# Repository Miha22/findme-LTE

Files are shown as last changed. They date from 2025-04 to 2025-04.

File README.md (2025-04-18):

# Low power LTE & GNSS anti-theft tracker

This project contains hardware design files, including schematics and PCB layouts created by Deniel.  
It is shared for educational and personal use purposes only. Commercial use is not permitted without written permission.

## Preview

The previews of the PCB design and schematic:

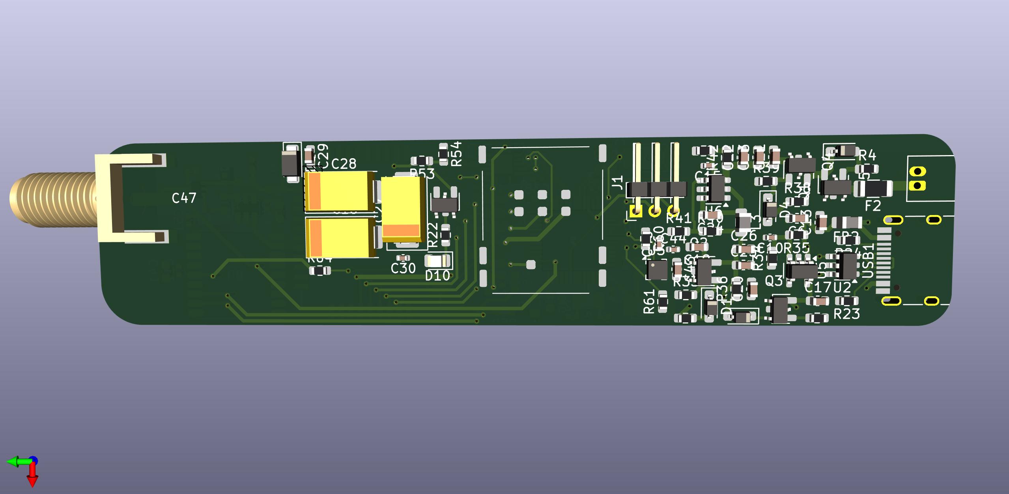
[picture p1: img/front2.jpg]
Board Front

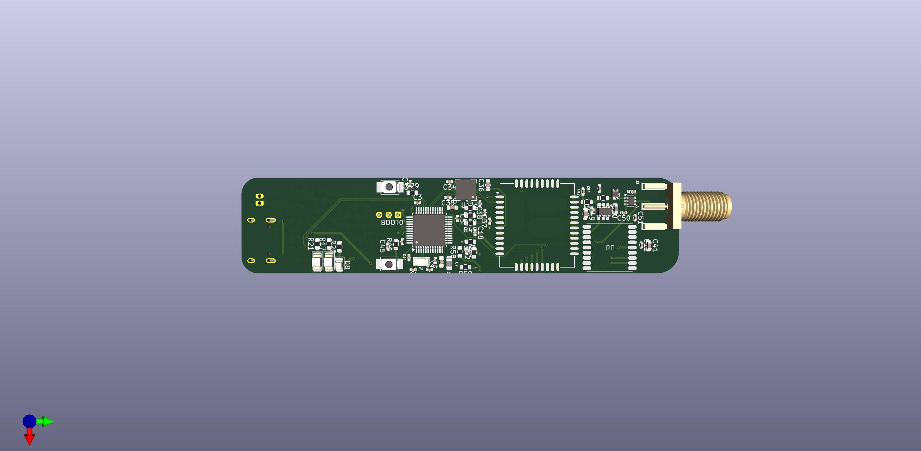
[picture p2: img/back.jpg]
Board Back

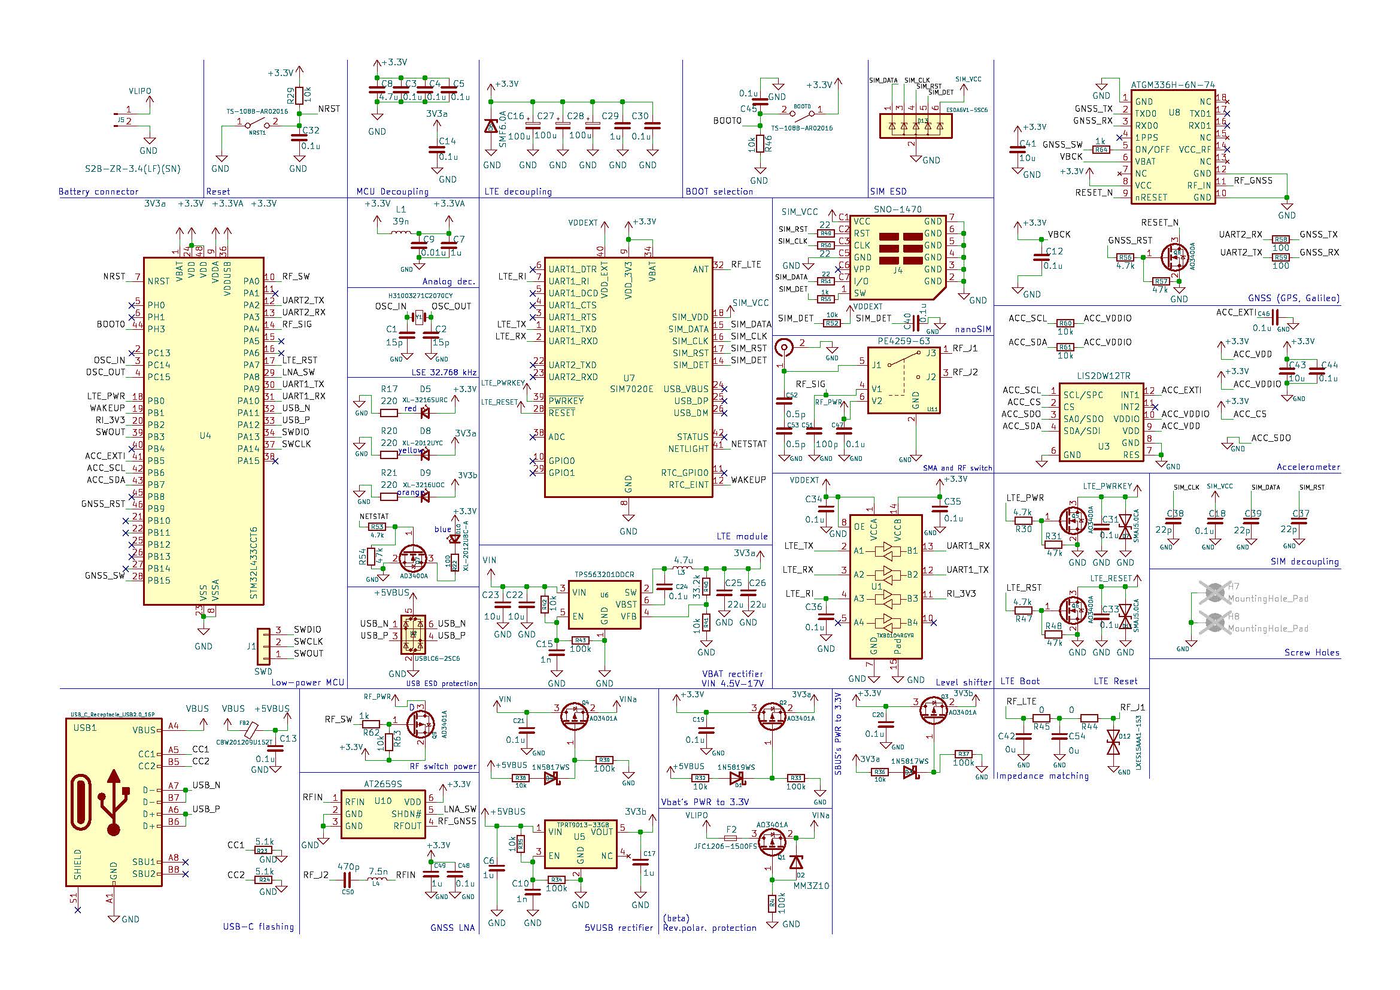
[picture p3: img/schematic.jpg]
Schematic


>  Note: The project is ongoing
> 1. Current schematic revision v0.3
> 2. Current PCB revision v0.1

## Description
Very compact __(20mm x 90mm)__ LTE modem designed to be used as anti-theft geolocation tracker to be mounted inside bicycles, moto, scooters etc. The UDP server and client to be setup and installed.

## Main Hardware
- MCU: STM32L433CCT6
- LTE: SIM7020**E**
- GNSS: ATGM336H-6N-74

## Notes for You
1. The design is still in Alpha state. New updates and revisions coming.
2. Firmware to be developed and tested as well as remote UDP server.
3. Real life Antenna test and adjustments needed, impedance matching has to be tuned (footprints are present).
4. Includes Design Rules errors due to **extreme size constraints**, take that in mind evaluating/redesigning the PCB. Keep width <25mm. 
5. All parts' datasheets have been analyzed. 
6. All parts are in stock on jlcpcb.com (except SIM7020E, but available on aliexpress for 9$+shipping).
7. Many drafts schematics are included in backups for you to see. Many failed because of incompatibility.

## License
This project is provided under a custom license based on the MIT License.  
Commercial use is prohibited. See the [LICENSE](./LICENSE) file for full details.

---

**Copyright © 2025 Deniel A.**

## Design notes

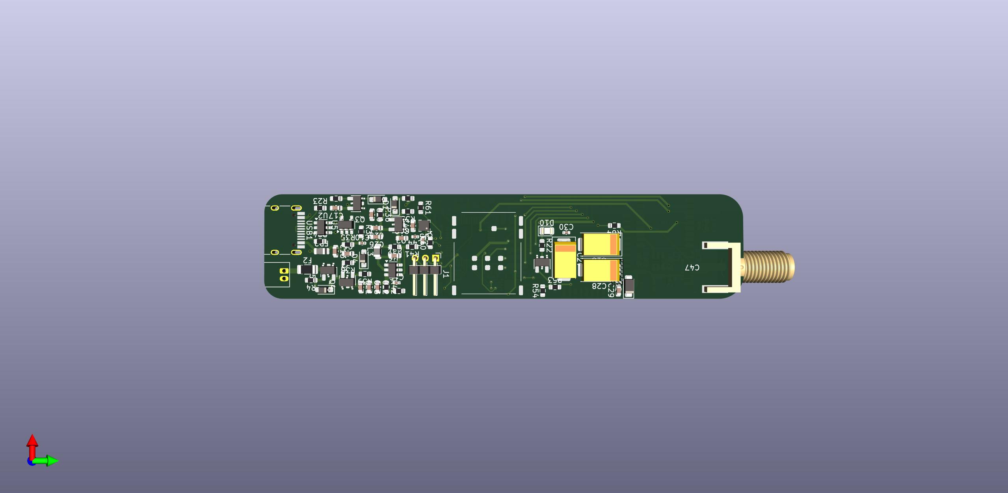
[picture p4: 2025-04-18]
img/front.jpg

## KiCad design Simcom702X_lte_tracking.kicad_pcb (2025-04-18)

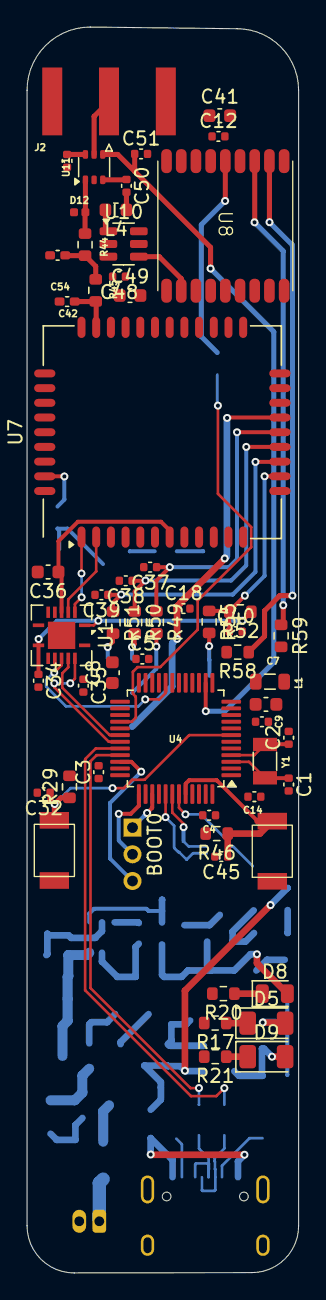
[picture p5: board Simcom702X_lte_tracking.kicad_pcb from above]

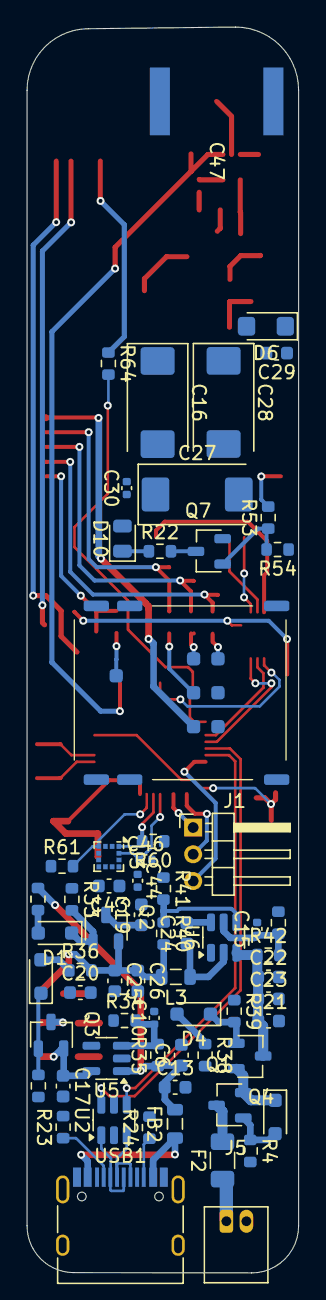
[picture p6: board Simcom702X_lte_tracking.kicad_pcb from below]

Board: 4 copper layers, 20.3 x 93.2 mm, 122 parts (64 on the bottom side), 78 nets.

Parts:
BOOT0: TS-1088-AR02016; SPST_39x30mm
C1, C2: 15p; C_0402_1005Metric
C3, C4, C5, C12, C14, C18, C30, C32, C34, C35, C40, C44, C45, C46, C47, C48: 0.1u; C_0402_1005Metric
C6, C7, C17, C29, C49: 1u; C_0603_1608Metric
C8: 4.7u; C_0603_1608Metric
C9: 0.01u; C_0402_1005Metric
C10, C15: 1n; C_0402_1005Metric
C13, C19, C20, C21, C24, C36: 0.1u; C_0603_1608Metric
C16, C27, C28: 100u; CP_EIA-7343-31_Kemet-D
C22, C23, C41, C43: 10u; C_0603_1608Metric
C25, C26: 22u; C_0603_1608Metric
C37, C38, C39: 22p; C_0402_1005Metric
C42, C54: 0u; C_0402_1005Metric_Pad0.74x0.62mm_HandSolder
C50: 470p; C_0402_1005Metric
C51: 100p; C_0402_1005Metric
D1: 1N5819WS; D_SOD-323_HandSoldering
D2: MM3Z10; D_SOD-323_HandSoldering
D3, D4: 1N5817WS; D_SOD-323_HandSoldering
D5: XL-3216SURC; LED_1206_3216Metric
D6: SMF6.0A; D_SMF
D8: XL-2012UYC; LED_0805_2012Metric
D9: XL-3216UOC; LED_1206_3216Metric
D10: XL-2012UBC-A; LED_0805_2012Metric
D12: LXES15AAA1-153; DFN1006-2L-BI
F2: JFC1206-1500FS; Fuse_1206_3216Metric
FB2: CBW201209U152T; L_0805_2012Metric
J1: SWD; PinHeader_1x03_P2.00mm_Horizontal
J2: SMA; SMA_Amphenol_132289_EdgeMount
J4: SNO-1470; nanoSIM_SNO-1470
J5: S2B-ZR-3.4(LF)(SN); JST_ZH_S2B-ZR_1x02_P1.50mm_Horizontal
L1: 39n; L_0805_2012Metric
L3: 4.7u; L_0805_2012Metric
L4: 7.5n; L_0603_1608Metric
NRST1: TS-1088-AR02016; SPST_39x30mm
Q1, Q2, Q3, Q4: AO3401A; SOT-23
Q7: AO3400A; SOT-23
R4, R33, R34, R37, R39, R43: 100k; R_0603_1608Metric
R17, R20, R21: 220; R_0603_1608Metric
R22, R58, R59: 100; R_0603_1608Metric
R23, R24: 5.1k; R_0603_1608Metric
R29, R32, R35, R36, R38, R41, R42, R46, R52, R60, R61: 10k; R_0603_1608Metric
R40: 33.2k; R_0603_1608Metric
R44, R45: 0; R_0603_1608Metric
R49, R50, R51: 22; R_0603_1608Metric
R53: 4.7k; R_0603_1608Metric
R54: 47k; R_0603_1608Metric
R55, R64: 1k; R_0603_1608Metric
U1: TXB0104RGYR; Texas_S-PVQFN-N14
U2: USBLC6-2SC6; SOT-23-6
U3: LIS2DW12TR; LGA-12_2x2mm_P0.5mm
U4: STM32L433CCT6; LQFP-48_7x7mm_P0.5mm
U5: TPRT9013-33GB; SOT-23-5
U6: TPS563201DDCR; SOT-23-6
U7: SIM7020E; SIMCom_SIM800C
U8: ATGM336H-6N-74; SMD_9.7x10.1mm_ATGM336H-6N-74
U10: AT2659S; SOT-23-6
U11: PE4259-63; SOT-363_SC-70-6
USB1: USB_C_Receptacle_USB2.0_16P; USB_C_Receptacle_HRO_TYPE-C-31-M-12
Y1: H31003271C2070CY; Crystal_SMD_3215-2Pin_3.2x1.5mm

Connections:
3V3a: C14.1, C25.1, C26.1, D8.2 (A), L3.2, Q2.2 (S), R36.2, R40.2, U4.1 (VBAT)
3V3b: C17.1, D9.2 (A), Q3.2 (S), U5.5 (VOUT)
+3.3V: BOOT0.1 (A), C3.1, C4.1, C5.1, C8.1, C12.1, C16.1, C19.1, C20.1, C27.1, C28.1, C29.1, C30.1, C35.1, C41.1, C43.1, C44.1, C48.1, C49.1, D5.2 (A), D6.1 (A1), D10.2 (A), L1.1, Q2.3 (D), Q3.3 (D), R29.2, R60.1, R61.1, U1.14 (VCCB), U3.2 (CS), U3.9 (VDD), U3.10 (VDDIO), U4.24 (VDD), U4.36 (VDDUSB), U4.48 (VDD), U7.9 (VDD_3V3), U7.34 (VBAT), U7.35 (VBAT), U8.6 (VBAT), U8.8 (VCC), U10.6 (VDD)
+3.3VA: C7.1, C9.1, L1.2, U4.9 (VDDA)
+5VBUS: C6.1, C13.1, FB2.2, R32.2, R35.1, R38.2, U2.5 (VBUS), U5.1 (VIN)
/ACC_EXTI: C46.1, U3.12 (INT1), U4.41 (PB5)
/ACC_SCL: R60.2, U3.1 (SCL/SPC), U4.42 (PB6)
/ACC_SDA: R61.2, U3.4 (SDA/SDI), U4.43 (PB7)
/BOOT0: BOOT0.2 (B), C45.1, R46.1, U4.44 (PH3)
/CC1: R23.1, USB1.A5 (CC1)
/CC2: R24.1, USB1.B5 (CC2)
/GNSS_RX: R59.1, U8.3 (RXD0)
/GNSS_SW: R64.2, U4.28 (PB15)
/GNSS_TX: R58.1, U8.2 (TXD0)
/LNA_SW: U4.29 (PA8), U10.5 (SHDN#)
/LTE_RI: C36.1, U1.4 (A3), U7.7 (UART1_RI)
/LTE_RX: U1.3 (A2), U7.2 (UART1_RXD)
/LTE_TX: U1.2 (A1), U7.1 (UART1_TXD)
/NETSTAT: R53.2, U7.41 (NETLIGHT)
/NRST: C32.1, NRST1.2 (B), R29.1, U4.7 (NRST)
/OSC_IN: C1.1, U4.3 (PC14), Y1.2
/OSC_OUT: C2.1, U4.4 (PC15), Y1.1
/RFIN: L4.2, U10.1 (RFIN)
/RF_GNSS: U8.11 (RF_IN), U10.4 (RFOUT)
/RF_J1: D12.2 (A2), R44.1, U11.1 (J3)
/RF_J2: C50.1, U11.3 (J2)
/RF_LTE: C42.1, R45.2, U7.32 (ANT)
/RF_SIG: C51.1, U4.14 (PA4), U11.4 (V1)
/RI_3V3: U1.11 (B3), U4.20 (PB2)
/SIM_CLK: C38.1, R50.1, U7.16 (SIM_CLK)
/SIM_DATA: C39.1, R51.1, U7.15 (SIM_DATA)
/SIM_DET: C40.1, R52.2, R55.1, U7.14 (SIM_DET)
/SIM_RST: C37.1, R49.1, U7.17 (SIM_RST)
/SWCLK: J1.2, U4.37 (PA14)
/SWDIO: J1.3, U4.34 (PA13)
/SWOUT: J1.1, U4.39 (PB3)
/UART1_RX: U1.13 (B1), U4.31 (PA10)
/UART1_TX: U1.12 (B2), U4.30 (PA9)
/UART2_RX: R58.2, U4.13 (PA3)
/UART2_TX: R59.2, U4.12 (PA2)
/USB_N: U2.1 (I/O1), U2.6 (I/O1), U4.32 (PA11), USB1.A7 (D-), USB1.B7 (D-)
/USB_P: U2.3 (I/O2), U2.4 (I/O2), U4.33 (PA12), USB1.A6 (D+), USB1.B6 (D+)
/WAKEUP: U4.19 (PB1), U7.12 (RTC_EINT)
GND: C1.2, C2.2, C3.2, C4.2, C5.2, C6.2, C7.2, C8.2, C9.2, C10.2, C12.2, C13.2, C14.2, C15.2, C16.2, C17.2, C18.2, C19.2, C20.2, C21.2, C22.2, C23.2, C25.2, C26.2, C27.2, C28.2, C29.2, C30.2, C32.2, C34.2, C35.2, C36.2, C37.2, C38.2, C39.2, C40.2, C41.2, C42.2, C43.2, C44.2, C45.2, C46.2, C47.2, C48.2, C49.2, C51.2, C54.2, D6.2 (A2), D12.1 (A1), J2.2 (Ext), J4.2 (GND), J4.3 (GND), J4.4 (GND), J4.5 (GND), J4.6 (GND), J4.7 (GND), J4.C5 (GND), J5.2, NRST1.1 (A), Q7.2 (S), R4.2, R17.2, R20.2, R21.2, R23.2, R24.2, R33.1, R34.1, R37.1, R39.1, R41.1, R43.1, R46.2, R54.1, U1.7 (GND), U1.15 (Pad), U2.2 (GND), U3.3 (SA0/SDO), U3.6 (GND), U3.7 (RES), U3.8 (GND), U4.8 (VSSA), U4.23 (VSS), U4.35 (VSS), U4.47 (VSS), U5.2 (GND), U6.1 (GND), U7.8 (GND), U7.13 (GND), U7.19 (GND), U7.21 (GND), U7.27 (GND), U7.30 (GND), U7.31 (GND), U7.33 (GND), U7.36 (GND), U7.37 (GND), U8.1 (GND), U8.10 (GND), U8.12 (GND), U10.2 (GND), U10.3 (GND), U11.2 (GND), USB1.A1 (GND), USB1.A12 (GND), USB1.B1 (GND), USB1.B12 (GND)
unnamed: C50.2, L4.1
unnamed: C54.1, R44.2, R45.1
unnamed: D1.2 (A), R32.1
unnamed: D1.1 (K), Q2.1 (G), R33.2
unnamed: D2.2 (A), Q1.1 (G), R4.1
unnamed: D3.2 (A), R36.1
unnamed: D3.1 (K), Q3.1 (G), R37.2
unnamed: D4.2 (A), R38.1
unnamed: D4.1 (K), Q4.1 (G), R39.2
unnamed: D5.1 (K), R17.1
unnamed: D8.1 (K), R20.1
unnamed: D9.1 (K), R21.1
unnamed: D10.1 (K), R22.1
unnamed: J2.1 (In), U11.5 (J1)
unnamed: J4.C3 (CLK), R50.2
unnamed: J4.C7 (I/O), R51.2
unnamed: J4.C2 (RST), R49.2
unnamed: J4.1 (SW), R55.2
unnamed: F2.2, Q1.3 (D)
unnamed: Q7.3 (D), R22.2
unnamed: Q7.1 (G), R53.1, R54.2
unnamed: C10.1, R34.2, R35.2, U5.3 (EN)
unnamed: C15.1, R42.2, R43.2, U6.5 (EN)
unnamed: C24.1, L3.1, U6.2 (SW)
unnamed: C24.2, U6.6 (VBST)
unnamed: R40.1, R41.2, U6.4 (VFB)
unnamed: R64.1, U8.5 (ON/OFF)
RF_PWR: C47.1, U11.6 (V2)
SIM_VCC: C18.1, J4.C1 (VCC), U7.18 (SIM_VDD)
VBUS: FB2.1, USB1.A4 (VBUS), USB1.A9 (VBUS), USB1.B4 (VBUS), USB1.B9 (VBUS)
VDDEXT: C34.1, R52.1, U1.1 (VCCA), U1.8 (OE), U7.40 (VDD_EXT)
VIN: C21.1, C22.1, C23.1, Q4.3 (D), R42.1, U6.3 (VIN)
VINa: D2.1 (K), Q1.2 (S), Q4.2 (S)
VLIPO: F2.1, J5.1
